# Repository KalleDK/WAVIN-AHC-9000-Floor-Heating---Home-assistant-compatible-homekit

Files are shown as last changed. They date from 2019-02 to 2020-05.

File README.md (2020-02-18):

# Credits
This fantastic project is not developed by me. The project is forked from this : https://github.com/dkjonas/Wavin-AHC-9000-mqtt

All the credits go to the originally owner "dkjonas". 

I made some modifications to this project, so the system integrates 3 led´s which can be used to indicate power, mqtt and wifi when all the electronics are mounted in a box. 

This project will recieve further updates. 

# Wavin-AHC-9000-mqtt
This is a simple Esp8266 mqtt interface for Wavin AHC-9000/Jablotron AC-116, with the goal of being able to control this heating controller from a home automation system.

## Hardware
The AHC-9000 uses modbus to communicate over a half duplex RS422 connection. It has two RJ45 connectors for this purpose, which can both be used. 
The following schematic shows how to connect an Esp8266 to the AHC-9000:
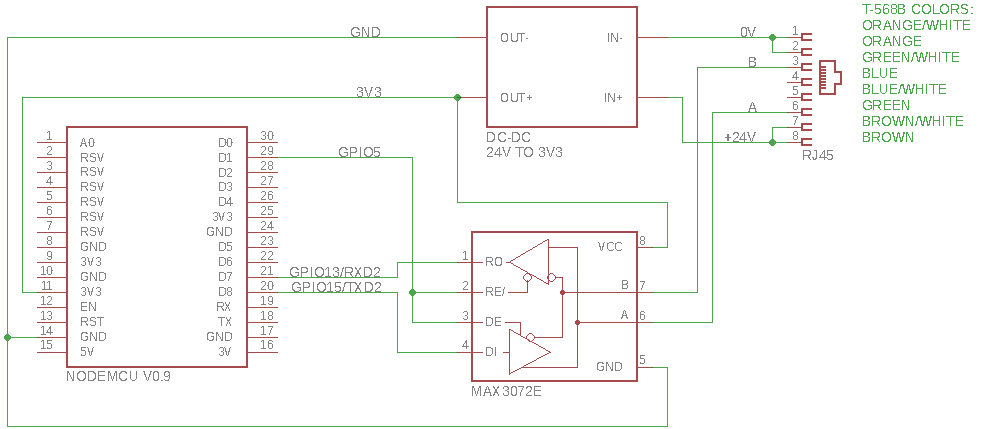
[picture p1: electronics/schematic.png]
Schematic


## Components with links to devices on Aliexpress

* Buck Converter : https://www.aliexpress.com/item/LM2596-LM2596S-LED-Voltmeter-ADJ-DC-DC-Step-down-Step-Down-Adjustable-Power-Supply-Module-With/32827909407.html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

* Tripler Base: https://www.aliexpress.com/item/TZT-Tripler-Base-V1-0-0-Module-Board-with-Pins-D1-Mini-Active-Components-Integrated-Circuits/32848786211.html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

* Protoboard-shield : https://www.aliexpress.com/item/ProtoBoard-Shield-for-WeMos-D1-mini-double-sided-perf-board-Compatible/32823336161.html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

* LED : https://www.aliexpress.com/item/Free-Ship-100PCS-2-3-4-2-5-7-Square-Transparent-LED-Red-Yellow-Green-Blue/32869433921.html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

* Thread M3 : https://www.aliexpress.com/item/100pcs-m3-3-4-5-6-8-OD-4-2mm-M3-Injection-Molding-Brass-Knurled-Thread/32813496424.html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

* M3 bolts.

* Modbus IC MAX3072E : https://www.aliexpress.com/item/MAX3072E-MAX3072EEPA-DIP/32859557410.html?spm=a2g0s.9042311.0.0.27424c4d1kt8zR

* DIP Socket : https://www.aliexpress.com/item/High-quality-20pcs-lot-8-Pins-DIP-DIP8-IC-Sockets-Adaptor-Solder-Type-8-PIN-IC/32822549802.html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

* WEMOS D1 mini or PRO or any ESP8266 device for that matter 

* 330R Resisitors

* RJ-45 Breakoutboard : https://www.aliexpress.com/item/Durable-Tap-Electronics-RJ45-Breakout-ModuleBoard-For-Arduino-New/32923930313.html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

* RJ-45 Socket : https://www.aliexpress.com/item/10Pcs-set-RJ45-Network-Ethernet-8P-8C-Female-Socket-Connectors-8Pin-PCB-Mount-RJ45-8P8C-Single/32850223640.html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

## Software

### Configuration

Watch the video (https://youtu.be/ePF0m4f8YUk)

### Compiling
I use [PlatformIO](https://platformio.org/) for compiling, uploading, and and maintaining dependencies for my code. If you install PlatformIO in a supported editor, building this project is quite simple. Just open the directory containing `platformio.ini` from this project, and click build/upload. If you use a different board than nodemcu, remember to change the `board` variable in `platformio.ini`.
You may be able to use the Arduino tools with the esp8266 additions for compiling, but a few changes may be needed, including downloading dependencies manually.

### Testing
Assuming you have a working mqtt server setup, you should now be able to control your AHC-9000 using mqtt. If you have the [Mosquitto](https://mosquitto.org/) mqtt tools installed on your mqtt server, you can execude:
```
mosquitto_sub -u username -P password -t heat/# -v
```
to see all live updated parameters from the controller.

To change the target temperature for a output, use:
```
mosquitto_pub -u username -P password -t heat/floorXXXXXXXXXXXX/1/target_set -m 20.5
```
where the number 1 in the above command is the output you want to control and 20.5 is the target temperature in degree celcius. XXXXXXXXXXXX is the MAC address of the Esp8266, so it will be unique for your setup.

### Integration with HomeAssistant
If you have a working mqtt setup in [HomeAssistant](https://home-assistant.io/), all you need to do in order to control your heating from HomeAssistant is to enable auto discovery for mqtt in your `configuration.yaml`.
```
mqtt:
  discovery: true
  discovery_prefix: homeassistant
```
You will then get a climate and a battery sensor device for each configured output on the controller.

If you don't like auto discovery, you can add the entries manually. Create an entry for each output you want to control. Replace the number 0 in the topics with the id of the output and XXXXXXXXXXXX with the MAC of the Esp8266 (can be determined with the mosquitto_sub command shown above)
```
climate wavinAhc9000:
  - platform: mqtt
    name: floor_kitchen
    current_temperature_topic: "heat/floorXXXXXXXXXXXX/0/current"
    temperature_command_topic: "heat/floorXXXXXXXXXXXX/0/target_set"
    temperature_state_topic: "heat/floorXXXXXXXXXXXX/0/target"
    mode_command_topic: "heat/floorXXXXXXXXXXXX/0/mode_set"
    mode_state_topic: "heat/floorXXXXXXXXXXXX/0/mode"
    modes:
      - "heat"
      - "off"
    availability_topic: "heat/floorXXXXXXXXXXXX/online"
    payload_available: "True"
    payload_not_available: "False"
    qos: 0

sensor wavinBattery:
  - platform: mqtt
    state_topic: "heat/floorXXXXXXXXXXXX/0/battery"
    availability_topic: "heat/floorXXXXXXXXXXXX/online"
    payload_available: "True"
    payload_not_available: "False"
    name: floor_kitchen_battery
    unit_of_measurement: "%"
    device_class: battery
    qos: 0
```

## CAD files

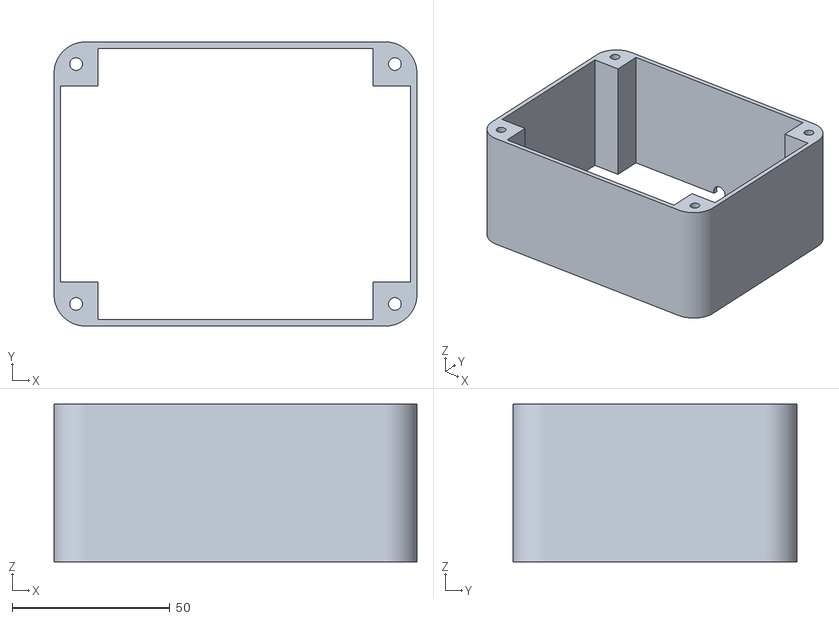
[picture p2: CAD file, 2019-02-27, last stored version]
stl_files/body.stl
115.0 x 90.0 x 50.0

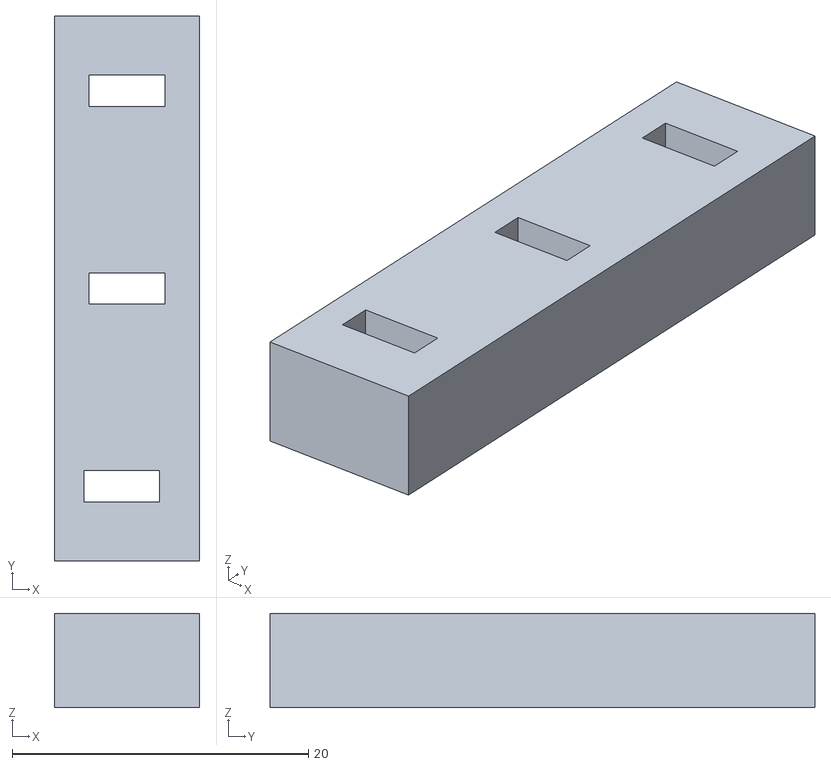
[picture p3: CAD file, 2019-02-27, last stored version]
stl_files/led_block.stl
9.80 x 36.8 x 6.37

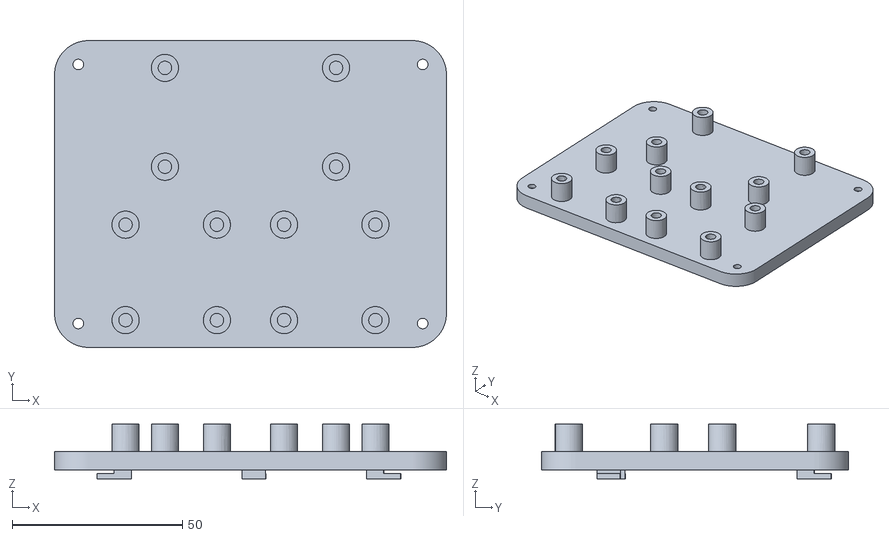
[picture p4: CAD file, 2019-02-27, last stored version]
stl_files/bottom.stl
115.0 x 90.0 x 16.0

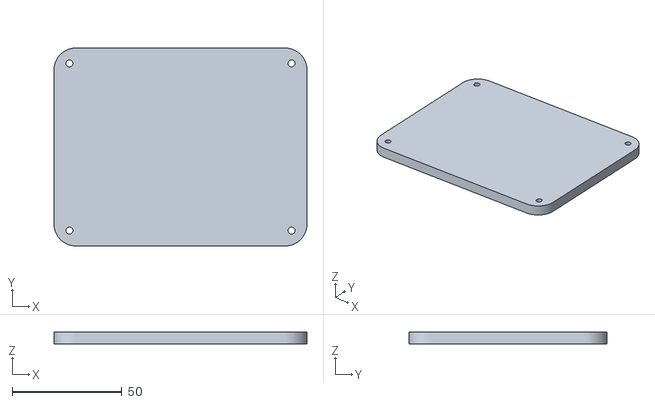
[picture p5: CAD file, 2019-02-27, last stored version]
stl_files/lid.stl
115.0 x 90.0 x 5.50

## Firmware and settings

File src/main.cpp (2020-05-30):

/*------------------------------------------------------------------------------
  16/02/2020
  Author: DKJONAS website https://github.com/dkjonas/Wavin-AHC-9000-mqtt
  Platforms: ESP8266
  Language: C++/Arduino
  ------------------------------------------------------------------------------
  Description: 

  This code provides an gateway to use with a Wavin AHC-9000 Floor Heating System. 
  The code sends data over MQTT, so you are able to use it with most Smart-Home platforms.
  This code / system runs very good on Home Assistant https://www.home-assistant.io

  ------------------------------------------------------------------------------
  Usage:

  The first time you flash this code, you will see an access point named "WavinAP".
  Connect to this network and follow the config-portal and fill out the forms.
  
  For more info from here look at the docs on the mentioned repositories.
  ------------------------------------------------------------------------------
  Thanks to these awesome people who helped with this code:

  https://github.com/heinekmadsen     
  https://github.com/dkjonas      
  https://github.com/paller

  ------------------------------------------------------------------------------
  License:
  Please see attached LICENSE.txt file for details.
  ------------------------------------------------------------------------------*/

#include <FS.h>
#include <LittleFS.h>
#include <DNSServer.h>
#include <ArduinoJson.h>
#include <ArduinoOTA.h>
#include <ESP8266WiFi.h>
#include <PubSubClient.h>
#include <ESP8266WebServer.h>
#include <WiFiManager.h>
#include <DoubleResetDetector.h>
#include "WavinController.h"
#include <Ticker.h>
 
/*------------------------------------------------------------------------------ 
TICKER SETUP - USED FOR SHOWING IF ESP IS IN CONFIG MODE OR NOT
------------------------------------------------------------------------------*/
 
Ticker ticker;
 
void tick()
{
  //toggle state
  int state = digitalRead(LED_BUILTIN);  // get the current state of GPIO1 pin
  digitalWrite(LED_BUILTIN, !state);     // set pin to the opposite state
}
 
//gets called when WiFiManager enters configuration mode
void configModeCallback (WiFiManager *myWiFiManager) {
  //Serial.println("Entered config mode");
  //Serial.println(WiFi.softAPIP());
  //if you used auto generated SSID, print it
  //Serial.println(myWiFiManager->getConfigPortalSSID());
  //entered config mode, make led toggle faster
  ticker.attach(0.2, tick);
}

/*------------------------------------------------------------------------------ 
DOUBLE RESET DETECTOR
------------------------------------------------------------------------------*/

// Number of seconds after reset during which a 
// subseqent reset will be considered a double reset.
#define DRD_TIMEOUT 10

// RTC Memory Address for the DoubleResetDetector to use
#define DRD_ADDRESS 0

DoubleResetDetector drd(DRD_TIMEOUT, DRD_ADDRESS);

/*------------------------------------------------------------------------------ 
// MQTT / WIFI / HOSTNAME DEFINES
------------------------------------------------------------------------------*/

// Esp8266 MAC will be added to the device name, to ensure unique topics
// Default is topics like 'heat/floorXXXXXXXXXXXX/3/target', where 3 is the output id and XXXXXXXXXXXX is the mac
const String   MQTT_PREFIX              = "heat/";       // include tailing '/' in prefix
const String   MQTT_DEVICE_NAME         = "floor";       // only alfanumeric and no '/'
const String   MQTT_ONLINE              = "/online";      
const String   MQTT_SUFFIX_CURRENT      = "/current";    // include heading '/' in all suffixes
const String   MQTT_SUFFIX_SETPOINT_GET = "/target";
const String   MQTT_SUFFIX_SETPOINT_SET = "/target_set";
const String   MQTT_SUFFIX_MODE_GET     = "/mode";
const String   MQTT_SUFFIX_MODE_SET     = "/mode_set";
const String   MQTT_SUFFIX_BATTERY      = "/battery";
const String   MQTT_SUFFIX_OUTPUT       = "/output";

const String   MQTT_VALUE_MODE_STANDBY  = "off";
const String   MQTT_VALUE_MODE_MANUAL   = "heat";

String   MQTT_CLIENT        = "Wavin-AHC-9000-mqtt"; // mqtt client_id prefix. Will be suffixed with Esp8266 mac to make it unique

char     MQTT_PORT[6]       = "1883";                // mqtt port = 1883 (Most used port)
String   WIFI_SSID          = "";                    // wifi ssid
String   WIFI_PASS          = "";                    // wifi password

String   MQTT_SERVER        = "";                    // mqtt server address without port number
String   MQTT_USER          = "";                    // mqtt user. Use "" for no username
String   MQTT_PASS          = "";                    // mqtt password. Use "" for no password

/*------------------------------------------------------------------------------ 
FLAGS AND CALLBACK FOR WIFIMANAGER
------------------------------------------------------------------------------*/

//flag for saving data
bool shouldSaveConfig = true;

//callback notifying us of the need to save config
void saveConfigCallback () {
  //Serial.println("Should save config");
  shouldSaveConfig = true;
}

/*------------------------------------------------------------------------------ 
CONTROL OF WAVIN
------------------------------------------------------------------------------*/

String mqttDeviceNameWithMac;
String mqttClientWithMac;

// Operating mode is controlled by the MQTT_SUFFIX_MODE_ topic.
// When mode is set to MQTT_VALUE_MODE_MANUAL, temperature is set to the value of MQTT_SUFFIX_SETPOINT_
// When mode is set to MQTT_VALUE_MODE_STANDBY, the following temperature will be used
const float STANDBY_TEMPERATURE_DEG = 5.0;

const uint8_t TX_ENABLE_PIN = 5;
const bool SWAP_SERIAL_PINS = true;
const uint16_t RECIEVE_TIMEOUT_MS = 1000;
WavinController wavinController(TX_ENABLE_PIN, SWAP_SERIAL_PINS, RECIEVE_TIMEOUT_MS);

WiFiClient wifiClient;
PubSubClient mqttClient(wifiClient);

unsigned long lastUpdateTime = 0;

const uint16_t POLL_TIME_MS = 5000;

struct lastKnownValue_t {
  uint16_t temperature;
  uint16_t setpoint;
  uint16_t battery;
  uint16_t status;
  uint16_t mode;
} lastSentValues[WavinController::NUMBER_OF_CHANNELS];

const uint16_t LAST_VALUE_UNKNOWN = 0xFFFF;

bool configurationPublished[WavinController::NUMBER_OF_CHANNELS];


// Read a float value from a non zero terminated array of bytes and
// return 10 times the value as an integer
uint16_t temperatureFromString(String payload)
{
  float targetf = payload.toFloat();
  return (unsigned short)(targetf * 10);
}


// Returns temperature in degrees with one decimal
String temperatureAsFloatString(uint16_t temperature)
{
  float temperatureAsFloat = ((float)temperature) / 10;
  return String(temperatureAsFloat, 1);
}


uint8_t getIdFromTopic(char* topic)
{
  unsigned int startIndex = String(MQTT_PREFIX + mqttDeviceNameWithMac + "/").length();
  int i = 0;
  uint8_t result = 0;

  while(topic[startIndex+i] != '/' && i<3)
  {
    result = result * 10 + (topic[startIndex+i]-'0');
    i++;
  }

  return result;
}


void mqttCallback(char* topic, byte* payload, unsigned int length)
{
  String topicString = String(topic);
  
  char terminatedPayload[length+1];
  for(unsigned int i=0; i<length; i++)
  {
    terminatedPayload[i] = payload[i];
  }
  terminatedPayload[length] = 0;
  String payloadString = String(terminatedPayload);

  uint8_t id = getIdFromTopic(topic);

  if(topicString.endsWith(MQTT_SUFFIX_SETPOINT_SET))
  {
    uint16_t target = temperatureFromString(payloadString);
    wavinController.writeRegister(WavinController::CATEGORY_PACKED_DATA, id, WavinController::PACKED_DATA_MANUAL_TEMPERATURE, target);
  }
  else if(topicString.endsWith(MQTT_SUFFIX_MODE_SET))
  {
    if(payloadString == MQTT_VALUE_MODE_MANUAL) 
    {
      wavinController.writeMaskedRegister(
        WavinController::CATEGORY_PACKED_DATA,
        id,
        WavinController::PACKED_DATA_CONFIGURATION,
        WavinController::PACKED_DATA_CONFIGURATION_MODE_MANUAL,
        ~WavinController::PACKED_DATA_CONFIGURATION_MODE_MASK);
    }
    else if (payloadString == MQTT_VALUE_MODE_STANDBY)
    {
      wavinController.writeMaskedRegister(
        WavinController::CATEGORY_PACKED_DATA, 
        id, 
        WavinController::PACKED_DATA_CONFIGURATION, 
        WavinController::PACKED_DATA_CONFIGURATION_MODE_STANDBY, 
        ~WavinController::PACKED_DATA_CONFIGURATION_MODE_MASK);
    }
  }

  // Force re-read of registers from controller now
  lastUpdateTime = 0;

}


void resetLastSentValues()
{
  for(int8_t i=0; i<WavinController::NUMBER_OF_CHANNELS; i++)
  {
    lastSentValues[i].temperature = LAST_VALUE_UNKNOWN;
    lastSentValues[i].setpoint = LAST_VALUE_UNKNOWN;
    lastSentValues[i].battery = LAST_VALUE_UNKNOWN;
    lastSentValues[i].status = LAST_VALUE_UNKNOWN;
    lastSentValues[i].mode = LAST_VALUE_UNKNOWN;

    configurationPublished[i] = false;
  }
}


void publishIfNewValue(String topic, String payload, uint16_t newValue, uint16_t *lastSentValue)
{
  if (newValue != *lastSentValue)
  {
    if (mqttClient.publish(topic.c_str(), payload.c_str(), true))
    {
        *lastSentValue = newValue;
    }
    else
    {
      *lastSentValue = LAST_VALUE_UNKNOWN;
    }
  }
}


// Publish discovery messages for HomeAssistant
// See https://www.home-assistant.io/docs/mqtt/discovery/
void publishConfiguration(uint8_t channel)
{
  String climateTopic = String("homeassistant/climate/" + mqttDeviceNameWithMac + "/" + channel + "/config");
  String climateMessage = String(
    "{\"name\": \"" +mqttDeviceNameWithMac + "_" + channel +  "_climate\", "
    "\"current_temperature_topic\": \"" + MQTT_PREFIX + mqttDeviceNameWithMac + "/" + channel + MQTT_SUFFIX_CURRENT + "\", " 
    "\"temperature_command_topic\": \"" + MQTT_PREFIX + mqttDeviceNameWithMac + "/" + channel + MQTT_SUFFIX_SETPOINT_SET + "\", " 
    "\"temperature_state_topic\": \"" + MQTT_PREFIX + mqttDeviceNameWithMac + "/" + channel + MQTT_SUFFIX_SETPOINT_GET + "\", " 
    "\"mode_command_topic\": \"" + MQTT_PREFIX + mqttDeviceNameWithMac + "/" + channel + MQTT_SUFFIX_MODE_SET + "\", " 
    "\"mode_state_topic\": \"" + MQTT_PREFIX + mqttDeviceNameWithMac + "/" + channel + MQTT_SUFFIX_MODE_GET + "\", " 
    "\"modes\": [\"" + MQTT_VALUE_MODE_MANUAL + "\", \"" + MQTT_VALUE_MODE_STANDBY + "\"], " 
    "\"availability_topic\": \"" + MQTT_PREFIX + mqttDeviceNameWithMac + MQTT_ONLINE +"\", "
    "\"payload_available\": \"True\", "
    "\"payload_not_available\": \"False\", "
    "\"qos\": \"0\"}"
  );
  
  String batteryTopic = String("homeassistant/sensor/" + mqttDeviceNameWithMac + "/" + channel + "/config");
  String batteryMessage = String(
    "{\"name\": \"" +mqttDeviceNameWithMac + "_" + channel +  "_battery\", "
    "\"state_topic\": \"" + MQTT_PREFIX + mqttDeviceNameWithMac + "/" + channel + "/battery\", " 
    "\"availability_topic\": \"" + MQTT_PREFIX + mqttDeviceNameWithMac + MQTT_ONLINE +"\", "
    "\"payload_available\": \"True\", "
    "\"payload_not_available\": \"False\", "
    "\"device_class\": \"battery\", "
    "\"unit_of_measurement\": \"%\", "
    "\"qos\": \"0\"}"
  );

  mqttClient.publish(climateTopic.c_str(), climateMessage.c_str(), true);  
  mqttClient.publish(batteryTopic.c_str(), batteryMessage.c_str(), true);
  
  configurationPublished[channel] = true;
}

/*------------------------------------------------------------------------------ 
SETUP
------------------------------------------------------------------------------*/
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
void loop()
{
  drd.stop();
  //Serial.begin(38400);
  if (WiFi.status() != WL_CONNECTED)
  {

    if (WiFi.waitForConnectResult() != WL_CONNECTED) return;
  }

  if (WiFi.status() == WL_CONNECTED)
  {

     // OTA
     ArduinoOTA.handle();

    //Serial.println("Wifi OK, checking mqtt...");
    if (!mqttClient.connected())
    {
      String will = String(MQTT_PREFIX + mqttDeviceNameWithMac + MQTT_ONLINE);
      if (mqttClient.connect(mqttClientWithMac.c_str(), MQTT_USER.c_str(), MQTT_PASS.c_str(), will.c_str(), 1, true, "False") )
      {
          //Serial.println("Connected to mqtt");
          String setpointSetTopic = String(MQTT_PREFIX + mqttDeviceNameWithMac + "/+" + MQTT_SUFFIX_SETPOINT_SET);
          mqttClient.subscribe(setpointSetTopic.c_str(), 1);
          
          String modeSetTopic = String(MQTT_PREFIX + mqttDeviceNameWithMac + "/+" + MQTT_SUFFIX_MODE_SET);
          mqttClient.subscribe(modeSetTopic.c_str(), 1);
          
          mqttClient.publish(will.c_str(), (const uint8_t *)"True", 4, true);

          // Forces resending of all parameters to server
          resetLastSentValues();
      }
      else
      {
          return;
      }
    }
  
    // Process incomming messages and maintain connection to the server
    if(!mqttClient.loop())
    {
        return;
    }

    if (lastUpdateTime + POLL_TIME_MS < millis())
    {
      lastUpdateTime = millis();

      uint16_t registers[11];

      for(uint8_t channel = 0; channel < WavinController::NUMBER_OF_CHANNELS; channel++)
      {
        if (wavinController.readRegisters(WavinController::CATEGORY_CHANNELS, channel, WavinController::CHANNELS_PRIMARY_ELEMENT, 1, registers))
        {
          uint16_t primaryElement = registers[0] & WavinController::CHANNELS_PRIMARY_ELEMENT_ELEMENT_MASK;
          bool allThermostatsLost = registers[0] & WavinController::CHANNELS_PRIMARY_ELEMENT_ALL_TP_LOST_MASK;

          if(primaryElement==0)
          {
              // Channel not used
              continue;
          }

          if(!configurationPublished[channel])
          {
            uint16_t standbyTemperature = STANDBY_TEMPERATURE_DEG * 10;
            wavinController.writeRegister(WavinController::CATEGORY_PACKED_DATA, channel, WavinController::PACKED_DATA_STANDBY_TEMPERATURE, standbyTemperature);
            publishConfiguration(channel);
          }

          // Read the current setpoint programmed for channel
          if (wavinController.readRegisters(WavinController::CATEGORY_PACKED_DATA, channel, WavinController::PACKED_DATA_MANUAL_TEMPERATURE, 1, registers))
          {
            uint16_t setpoint = registers[0];

            String topic = String(MQTT_PREFIX + mqttDeviceNameWithMac + "/" + channel + MQTT_SUFFIX_SETPOINT_GET);
            String payload = temperatureAsFloatString(setpoint);

            publishIfNewValue(topic, payload, setpoint, &(lastSentValues[channel].setpoint));
          }

          // Read the current mode for the channel
          if (wavinController.readRegisters(WavinController::CATEGORY_PACKED_DATA, channel, WavinController::PACKED_DATA_CONFIGURATION, 1, registers))
          {
            uint16_t mode = registers[0] & WavinController::PACKED_DATA_CONFIGURATION_MODE_MASK; 

            String topic = String(MQTT_PREFIX + mqttDeviceNameWithMac + "/" + channel + MQTT_SUFFIX_MODE_GET);
            if(mode == WavinController::PACKED_DATA_CONFIGURATION_MODE_STANDBY)
            {
              publishIfNewValue(topic, MQTT_VALUE_MODE_STANDBY, mode, &(lastSentValues[channel].mode));
            }
            else if(mode == WavinController::PACKED_DATA_CONFIGURATION_MODE_MANUAL)
            {
              publishIfNewValue(topic, MQTT_VALUE_MODE_MANUAL, mode, &(lastSentValues[channel].mode));
            }            
          }

          // Read the current status of the output for channel
          if (wavinController.readRegisters(WavinController::CATEGORY_CHANNELS, channel, WavinController::CHANNELS_TIMER_EVENT, 1, registers))
          {
            uint16_t status = registers[0] & WavinController::CHANNELS_TIMER_EVENT_OUTP_ON_MASK;

            String topic = String(MQTT_PREFIX + mqttDeviceNameWithMac + "/" + channel + MQTT_SUFFIX_OUTPUT);
            String payload;
            if (status & WavinController::CHANNELS_TIMER_EVENT_OUTP_ON_MASK)
              payload = "on";
            else
              payload = "off";

            publishIfNewValue(topic, payload, status, &(lastSentValues[channel].status));
          }

          // If a thermostat for the channel is connected to the controller
          if(!allThermostatsLost)
          {
            // Read values from the primary thermostat connected to this channel 
            // Primary element from controller is returned as index+1, so 1 i subtracted here to read the correct element
            if (wavinController.readRegisters(WavinController::CATEGORY_ELEMENTS, primaryElement-1, 0, 11, registers))
            {
              uint16_t temperature = registers[WavinController::ELEMENTS_AIR_TEMPERATURE];
              uint16_t battery = registers[WavinController::ELEMENTS_BATTERY_STATUS]; // In 10% steps

              String topic = String(MQTT_PREFIX + mqttDeviceNameWithMac + "/" + channel + MQTT_SUFFIX_CURRENT);
              String payload = temperatureAsFloatString(temperature);

              publishIfNewValue(topic, payload, temperature, &(lastSentValues[channel].temperature));

              topic = String(MQTT_PREFIX + mqttDeviceNameWithMac + "/" + channel + MQTT_SUFFIX_BATTERY);
              payload = String(battery*10);

              publishIfNewValue(topic, payload, battery, &(lastSentValues[channel].battery));
            }
          }         
        }

        // Process incomming messages and maintain connection to the server
        if(!mqttClient.loop())
        {
            return;
        }
      }
    }
  }
}

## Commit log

2019-05-18 update notes for LED´s
2019-05-18 Put config of led´s in seperate file
2019-05-18 Update for LED file
2019-05-18 ledconfig update
2019-05-21 Update whole code with more simple status LED´s
2019-05-21 Update whole code to more simple status LED´s and include PIN setup in privateconfig.h
2019-05-21 Set led pin d3 to high when not using builtin led
2020-02-12 Revert "Update to Wifimanager"
    This reverts commit 05da93c4a6377f651d2ac2de4612a967a93be1ff.
    [main.cpp]
2020-02-12 Revert "Revert "Update to Wifimanager""
    This reverts commit c1258b9e1edb4635d2b83e1ae72ae59c446b3a05.
    [main.cpp]
2020-02-17 Updated code to be used with ArduinoJson v.6
    + minor fixes
